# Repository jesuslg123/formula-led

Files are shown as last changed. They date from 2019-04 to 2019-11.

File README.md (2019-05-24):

# Formula LED

See the project on Hackster.io: https://www.hackster.io/xing-hackweek/formula-led-b4cd78

## Team Members

### Dev Team

* [jesus-lopez](https://github.com/jesuslg123)
* [aaron-ciaghi](https://github.com/aaronsama)
* [sarah-seitz](https://github.com/SarahNox)
* [isobel-smith](https://github.com/IzzySmith)

### Special thanks to contributors

* jordi-manuel
* [helios-aliaga](https://github.com/heliosam)

## Rules

* There are two players: red and blue
* The race begins with a random countdown
* Keep pressing the button on the controller to accelerate
* When a player goes too fast it changes color to green or yellow
* Keep going too fast to be "thrown off the track". When this happens the player's speed is reset to 0 and the player blinks until it accelerates back to speed 1
* There are 5 laps in a race
* The first player to cross the line at the end of the 4th lap wins
* Press the reset button to start again

## Build your own

You will need:

* Hardware:
  * 1x Arduino Nano (or any Arduino)
  * 1x LED Strip (WS2813)
  * 2x Buttons
  * 1x 1000 µF capacitor
  * 2x 10kΩ resistors (for the buttons)
  * 1x 470Ω resistor (for the LED strip) but change it according to your power supply
  * Optional: 5V 2A power supply (you may have to change the resistors and the capacitor)
  * All the necessary cables to connect all the stuff above
* Components you can 3d-print:
  * Controllers ([Player 1](https://source.xing.com/hackweek/arduino-led-racing/blob/master/3D/Player%201.stl), [Player 2](https://source.xing.com/hackweek/arduino-led-racing/blob/master/3D/Player%202.stl))
  * Base
* Software:
  * Arduino IDE
  * Fritzing (http://fritzing.org/download/)

Follow the designs in: [Schemas](./Schemas)

## A real-time race event board

We want to display the race progress in real time on a race board. To do this we are using Flask, (http://flask.pocoo.org/), and mqtt-messages.

##### Requirements

`Python3` and `pip` are installed.

Create your virtual environment.

`<venv>` in this case is the path to your virtual environment. (For simplicity, this can just be `venv`)

```
python3 -m venv <venv>
```

##### Local Development

##### Local, Local

To activate the virtual environment:

```
source <venv>/bin/activate
```

To run the application:

```
export FLASK_APP=race_events
export FLASK_ENV=development
pip install -e .
flask run
```

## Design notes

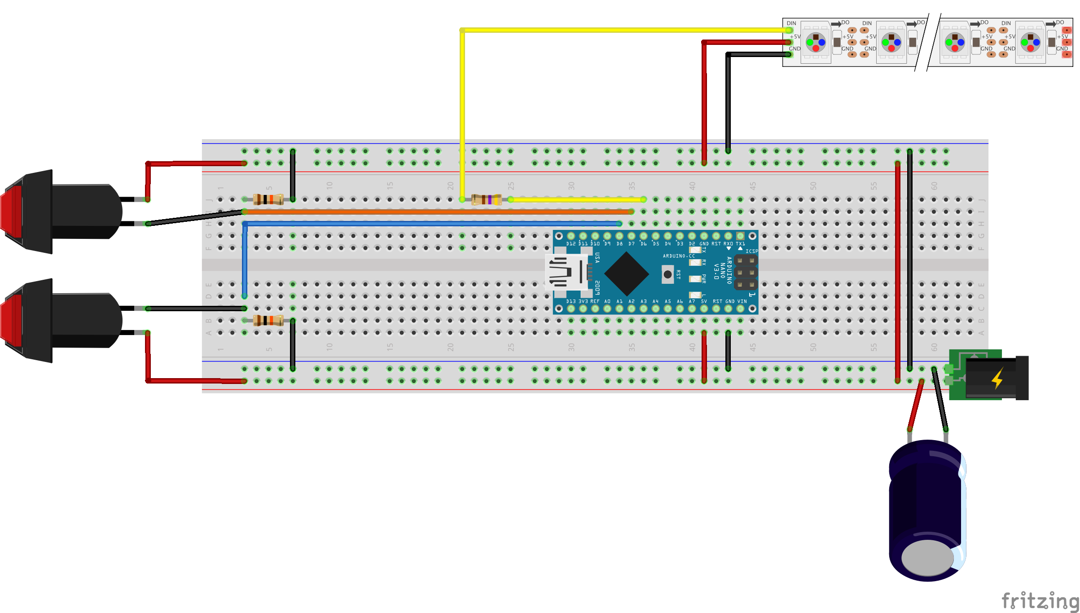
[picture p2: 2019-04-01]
Schemas/LEDRACE_bb.png

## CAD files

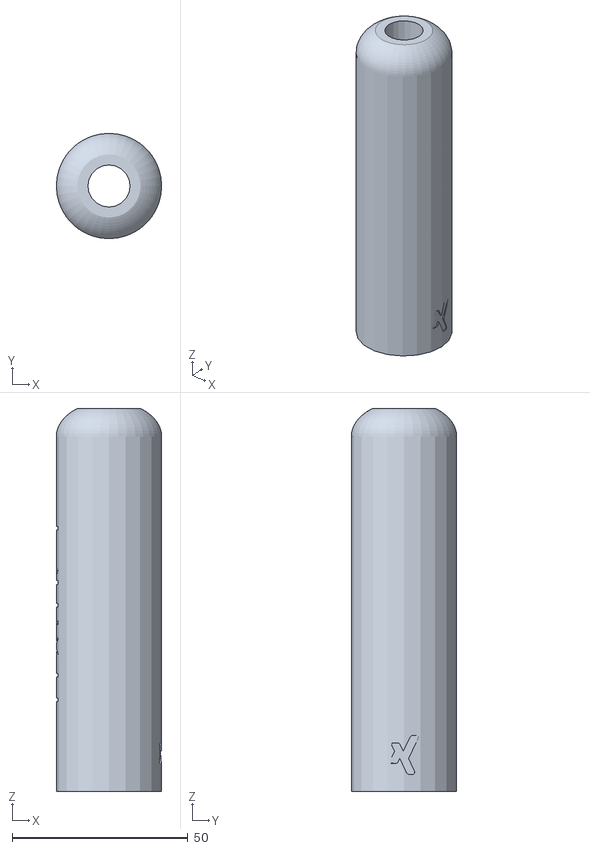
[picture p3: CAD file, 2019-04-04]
3D/Player 1.stl
30.0 x 30.0 x 109.0

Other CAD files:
3D/Player 2.stl

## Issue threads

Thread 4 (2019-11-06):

More documentation (plus global schema) is needed

jrierab, 2019-11-06:
First of all, I like very much how the project is structured and programmed. It would be very easy to extend it and add 2 new players, or other functionalities as needed (I am thinking about a demo race, when nobody is playing).

However, the README and documentation feels incomplete. If I read the code correctly, there are 2 Arduino boards and 1 external PC involved in the full setup:

- One Arduino board is needed for the led-race. This board sends info through the serial port to a second arduino board.
- The second Arduino board receives that info from serial the port, and connects via wifi to an external PC (sending MQTT tokens).
- The PC receives the data via a python server and updates a web page.

I would appreciate a global diagram and a brief comment about the intended setup.

jesuslg123, 2019-11-09:
Hello @jrierab ! We are really happy you like the project.

Thank you so much for all your suggestions, you are right about the full setup, 2 Arduino and 1 computer and involved on the full setup.

We will try to propose a new `readme` with more details as soon as possible, meanwhile, please feel free to contact us or request information through the repo.

Again, thanks you!

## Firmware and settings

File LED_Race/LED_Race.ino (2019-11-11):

#include <FastLED.h>

#include "constants.h"
#include "player.h"
#include "draw.h"
#include "melody.h"

struct Player player1;
struct Player player2;

int raceCountdown = 0;
boolean raceStarting = true;
boolean raceFinished = false;

void setup() {
  pinMode(PLAYER1_PIN,INPUT_PULLUP); 
  pinMode(PLAYER2_PIN,INPUT_PULLUP);  

  Serial.begin(9600);
  setupSpeaker();
  
  initPlayer(&player1, 1, PLAYER1_PIN, CRGB::Red, CRGB::Green);
  initPlayer(&player2, 2, PLAYER2_PIN, CRGB::Blue, CRGB::Yellow);

  setupTrack();
}

void loop() {
  if (raceStarting) {
      doRaceStartSequence();
  } else if (raceFinished) {
      doRaceEndingSequence();
  } else {
      doRaceRun();
  }
}

void doRaceStartSequence() {
  drawCountdown(raceCountdown);
  raceStartSound(raceCountdown);

  delay(1000);

  raceCountdown++;

  if (raceCountdown == 3) {
    Serial.println("<S, 0, 0>");  
    raceStarting = false;
    raceCountdown = 0;
  }
}
  
void doRaceEndingSequence() {
    delay(1000);
    raceCountdown++;
    if (raceCountdown == 5) {
      raceFinished = false;
      raceCountdown = 0;
      initPlayer(&player1, 1, PLAYER1_PIN, CRGB::Red, CRGB::Green);
      initPlayer(&player2, 2, PLAYER2_PIN, CRGB::Blue, CRGB::Yellow);
    }
}

void doRaceRun() {
  movePlayer(&player1);
  movePlayer(&player2);
  drawPlayer(&player1);
  drawPlayer(&player2);

  playerBeep(player1.id, player1.speed);
  playerBeep(player2.id, player2.speed);

  if (isRaceFinished()) {
    struct Player winner = findWinner(player1, player2);
    drawWinner(&winner);
    raceFinished = true;

    raceEndSound();
  }

  delay(15);
}

void initPlayer(struct Player *player, int id, int pin, CRGB::HTMLColorCode color, CRGB::HTMLColorCode highSpeedColor) {
  player->id = id;
  player->buttonPin = pin;
  player->buttonState = LOW;
  player->prevPosition = 0;
  player->position = 0;
  player->loop = 0;
  player->speed = 0.0;
  player->isWinner = false;
  player->isOffTrack = false;
  player->blinking = false;
  player->color = color;
  player->highSpeedColor = highSpeedColor;
}

boolean buttonReleased(struct Player *player) {
  int previousState = player->buttonState;
  player->buttonState = digitalRead(player->buttonPin);

  if (previousState == HIGH && player->buttonState == LOW) {
    return true;
  }

  return false;
}

void movePlayer(struct Player *player) {
  if (buttonReleased(player)) {
    player->speed += ACCELERATION; // acceleration

    if (player->isOffTrack) {
      player->blinking = !(player->blinking);
    }
  }

  player->speed -= player->speed * FRICTION;

  if (player->speed < 0) {
    player->speed = 0;
  } else if (player->speed >= MAX_SPEED) {
    player->speed = 0;
    player->isOffTrack = true;
  }

  player->prevPosition = player->position;
  player->position = (int)(player->position + player->speed) % NUM_LEDS;

  if (player->position < player->prevPosition) {
    player->loop += 1;
    Serial.println("<L, " + (String)(player->id) + ", " + (String)(player->loop) + ">");
  }

  if (player->loop == MAX_LOOPS) {
    player->isWinner = true;
    Serial.println("<W, " + (String)(player->id) + ", 0>");
  }

  Serial.println("<P, " + (String)(player->id) + ", " + (String)(player->speed) + ">");
}

boolean isRaceFinished() {
  return player1.isWinner || player2.isWinner;
}

struct Player findWinner(struct Player player1, struct Player player2) {
  if (player1.isWinner) {
    return player1;
  } else if (player2.isWinner) {
    return player2;
  }
}

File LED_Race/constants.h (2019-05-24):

#define ACCELERATION 0.4
#define FRICTION 0.03
#define MAX_SPEED 3.6
#define MAX_LOOPS 5
#define HIGHSPEED 3

#define NUM_LEDS 300
#define LED_PIN 4
#define PLAYER1_PIN 6
#define PLAYER2_PIN 7

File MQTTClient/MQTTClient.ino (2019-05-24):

#include "mqtt.h"
#include "wifi.h"

// see https://forum.arduino.cc/index.php?topic=396450

const byte numChars = 32;
char receivedChars[numChars];
char tempChars[numChars];        // temporary array for use when parsing

// variables to hold the parsed data
char message[numChars] = {0};
int playerId = 0;

float lastSpeeds[2] = { -1.0, -1.0 };

float playerSpeed = 0.0;

boolean newData = false;

void setup() {
  // put your setup code here, to run once:
  Serial.begin(9600);
  
  connectWifi();
  setupMQTT();
}

void loop() {
  recvWithStartEndMarkers();
  if (newData == true) {
    strcpy(tempChars, receivedChars);
    // this temporary copy is necessary to protect the original data
    //   because strtok() used in parseData() replaces the commas with \0
    parseData();
    parsedDataToMQTTMessage();
    newData = false;
  }
}

//============

void recvWithStartEndMarkers() {
  static boolean recvInProgress = false;
  static byte ndx = 0;
  char startMarker = '<';
  char endMarker = '>';
  char rc;

  while (Serial.available() > 0 && newData == false) {
    rc = Serial.read();

    if (recvInProgress == true) {
      if (rc != endMarker) {
        receivedChars[ndx] = rc;
        ndx++;
        if (ndx >= numChars) {
          ndx = numChars - 1;
        }
      }
      else {
        receivedChars[ndx] = '\0'; // terminate the string
        recvInProgress = false;
        ndx = 0;
        newData = true;
      }
    }

    else if (rc == startMarker) {
      recvInProgress = true;
    }
  }
}

//============

void parseData() {      // split the data into its parts
  char * strtokIndx; // this is used by strtok() as an index

  strtokIndx = strtok(tempChars, ",");     // get the first part - the string
  strcpy(message, strtokIndx); // copy it to messageFromPC

  strtokIndx = strtok(NULL, ","); // this continues where the previous call left off
  playerId = atoi(strtokIndx);     // convert this part to an integer

  strtokIndx = strtok(NULL, ",");
  playerSpeed = atof(strtokIndx);     // convert this part to a float
}

//============

void parsedDataToMQTTMessage() {
  // debug (rebuild message)
//  Serial.print("<");
//  Serial.print(message[0]);
//  Serial.print(", ");
//  Serial.print(playerId);
//  Serial.print(", ");
//  Serial.print(playerSpeed);
//  Serial.println(">");
  connectMQTT();
  
  if (message[0] == 'P') {
    if (lastSpeeds[playerId - 1] != playerSpeed) {
      lastSpeeds[playerId - 1] = playerSpeed;
      mqttPlayerSpeed(playerId, playerSpeed);
    }
  } else if (message[0] == 'S') {
    mqttStart();
  } else if (message[0] == 'W') {
    mqttEnd(playerId);
  } else if (message[0] == 'L') {
    int playerLoop = (int)playerSpeed;
    mqttLoop(playerId, playerLoop);
  }
}

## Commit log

2019-04-02 change track color when there is a winner
2019-04-03 add explosion when off track
2019-04-04 better readme
    [LEDRACE.fzz]
2019-04-04 Added 3D models
    [Player 1.stl, Player 2.stl]
2019-05-22 send msg through serial to play sounds on another Arduino
2019-05-22 fix race sounds and add debug statements
    [SoundsPlayer.ino, melody.cpp]
2019-05-23 open the socket connection
2019-11-06 feat: Adds internal pull-up resistor to the input pìns
    The external resistors are not needed anymore.
